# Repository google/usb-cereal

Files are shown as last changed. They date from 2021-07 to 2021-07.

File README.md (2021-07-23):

# USB-Cereal

USB-Cereal is a debugging and development tool for designs that use USB-C port and bring out serial TX/RX lines into SBU1/2 pins. USB-Cereal is made compatible with both 1.8V and 3.3V signalling.

A few important things to note:

* **USB-Cereal is not an officially supported Google product.**

* **USB-Cereal will not work as a USB-C hub/splitter. It is a development tool.**

* **USB-Cereal device is not USB-C spec compliant tool. It will not work with and might damage target devices that hasn't been designed to work with USB-Cereal. Please use with caution and at your own risk.**

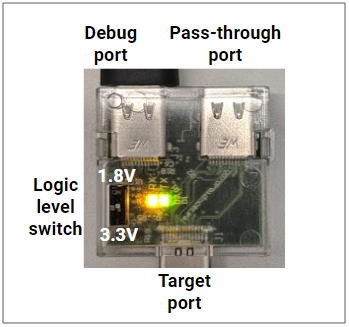
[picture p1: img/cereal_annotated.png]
Cereal Annotated


Please read getting started before plugging in the device. If used without caution, both USB-Cereal and target device could be damaged.

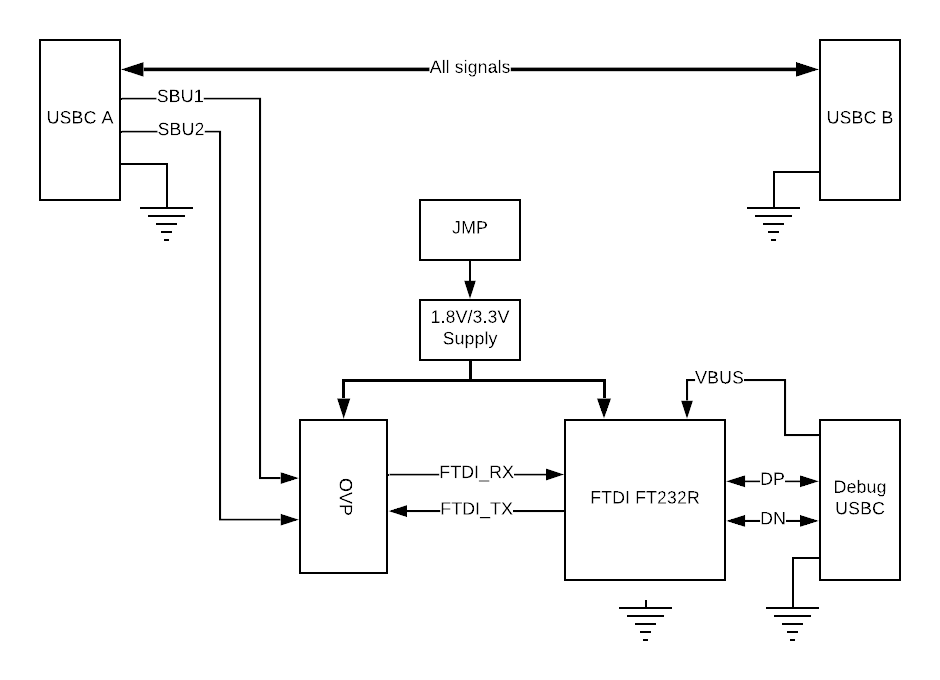
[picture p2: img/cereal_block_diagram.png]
Cereal Block Diagram


# Getting Started
1. Determine correct serial signalling level on the target device - 1.8V or 3.3V. Incorrect voltage setting might permanently damage your device!
2. Determine correct orientation - top vs. bottom - the tool operates correctly only when SBU1 pin corresponds to TX and SBU2 pin corresponds to RX.
3. Serial log capture - please install ftdi232r [drivers](https://www.ftdichip.com/Drivers/VCP.htm). Use your favorite serial monitoring console on the PC.

# Avoid Damaging Target Device
USB-Cereal can operate both with 1.8V and 3.3V logic level systems. The transition from 1.8V to 3.3V is NOT automatic and is done via on-board DIP switch. **Incorrect logic level setting might cause target device or USB-Cereal failure and/or permanent damage. If unsure of target device logic levels used, always start with 1.8V to avoid damaging the target device.** USB-Cereal implements overvoltage clamp transistors, and is unlikely to get damaged from small overvoltage events.

# Source Files
1. Schematic diagram + board layout (Altium)
2. Enclosure (STLs, STEP file exported from Autocad Fusion 360)
3. No firmware/programming is required

# License
This project is licensed under the Apache v2.0 License - see the [LICENSE.md](LICENSE.md) file for details

# Contributing
Thank you for your interest - please review CONTRIBUTING.md!

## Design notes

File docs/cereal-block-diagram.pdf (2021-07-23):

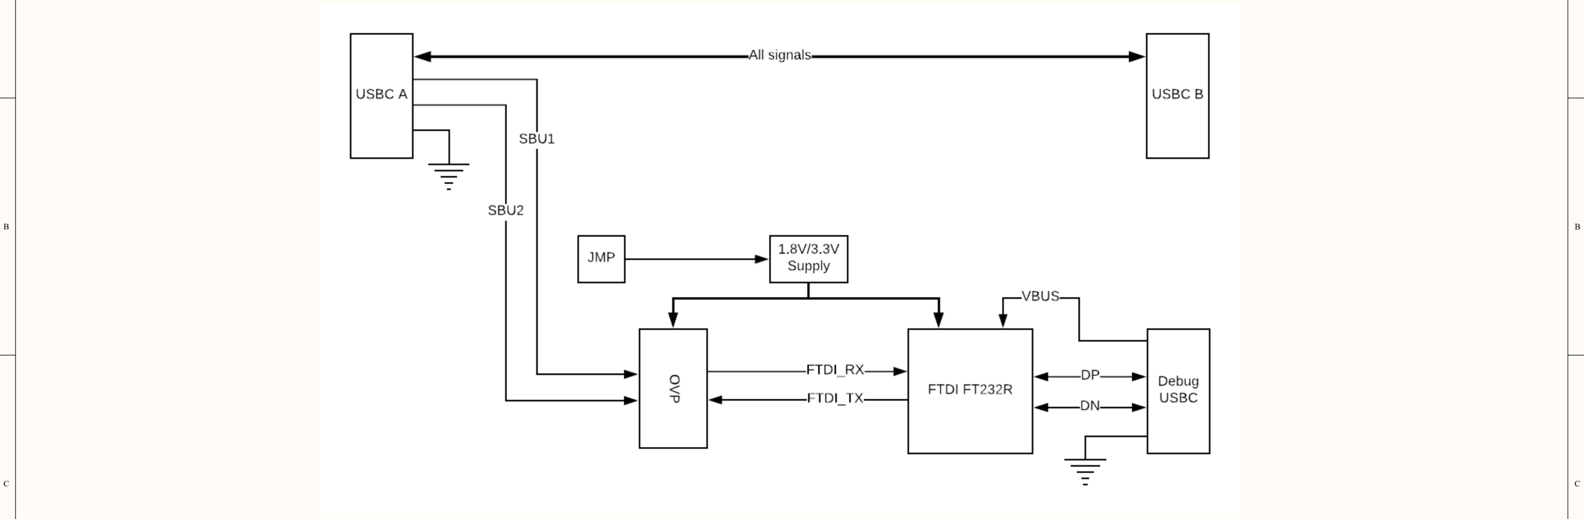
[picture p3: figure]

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
Cereal Diagram

N/A | 1
5/13/2020 | 5:09:34 PM

Title:

GPN: | Size:

Date:

Revision:

Time: | Sheet | of

Tabloid

Author:

Reviewers:

dnv

elerner, jmpenny

Utility board that provides serial interface tapped into SBU lines, compatible with both 1.8V and 3.3V signalling.

Cereal - USB-C serial interface breakout for debugging/development purposes.

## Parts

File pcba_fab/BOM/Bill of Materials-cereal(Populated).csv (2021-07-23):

Comment | Description | Designator | Footprint | LibRef | Quantity
1µF | CAP CER 1UF 6.3V X5R 0201 | C1, C2, C9, C10 | SMD-0201C | GRM033R60J105MEA2D | 4
0.10µF | CAP CER 0.1UF 10V X5R 0201 | C3, C5 | SMD-0201C | GRM033R61A104KE15D | 2
4.7µF | CAP CER 4.7UF 4V X5R 0402 | C4 | SMD-0402C | GRM153R60G475ME15D | 1
10000pF | CAP CER 10000PF 10V X5R 0201 | C6 | SMD-0201C | GRM033R61A103KA01J | 1
2.2µF | CAP CER 2.2UF 10V X5R 0201 | C7, C8 | SMD-0201C | GRM033R61A225KE47D | 2
LTST-C171GKT | LED | D1 | 0805 | LTST-C171GKT | 1
LTST-C171KSKT | LED | D2 | 0805 | LTST-C171KSKT | 1
MBD54DWT1 | Dual Schottky Barrier Diodes, 6-Pin SOT-363, Tape and Reel | D5 | ONSC-SOT-363-6-419B-02_W_V | MBD54DWT1 | 1
632712000011 | USB 3.1 Type C Plug Horizontal SMT WR-COM | J1 | 632712000011 | 632712000011 | 1
632723100011 | USB 3.1 Type C Receptacle Horizontal THR WR-COM | J2, J3 | 632723100011 | 632723100011 | 2
PMDXB600UNEZ | Dual N-Channel Trench MOSFET, 20 V, 0.6 A, -55 to 150 degC, 8-Pin SOT1216 | Q1, Q2 | NXP-SOT1216_N | PMDXB600UNEZ | 2
0.0 | RES SMD 0.0OHM JUMPER 1/20W 0201 | R1, R2, R7, R8, R16 | SMD-0201-RES | ERJ-1GN0R00C | 5
62 | RES SMD 62 OHM 5% 1/10W 0402 | R3, R4 | SMD-0402-RES | ERJ-2GEJ620X | 2
1k | RES SMD 1K OHM 1% 1/20W 0201 | R5 | SMD-0201-RES | ERJ-1GEF1001C | 1
270 | RES SMD 270 OHM 1% 1/20W 0201 | R6 | SMD-0201-RES | ERJ-1GEF2700C | 1
53.6k | RES SMD 53.6K OHM 1% 1/20W 0201 | R9, R10 | SMD-0201-RES | ERJ-1GEF5362C | 2
22.1k | RES SMD 22.1K OHM 1% 1/20W 0201 | R11 | SMD-0201-RES | ERJ-1GEF2212C | 1
30.1k | RES SMD 30.1K OHM 1% 1/20W 0201 | R12, R15, R17, R19 | SMD-0201-RES | ERJ-1GEF3012C | 4
5.1k | RES SMD 5.1K OHM 1% 1/20W 0201 | R18, R20 | SMD-0201-RES | ERJ-1GEF5101C | 2
416131160801 | WS-DISV 1.27 mm small compact SMD Dip Switch with top tape | SW1 | 416131160801 | 416131160801 | 1
ESDR0502NMUTAG | Ultra Low Capacitance ESD Protection Array for High Speed Data Line Protection, 6-Pin UDFN, Pb-Free, Tape and Reel | U1 | ONSC-UDFN-6-517AA-01_V | ESDR0502NMUTAG | 1
TPS77401DGK | Single Output Fast Transient Response LDO, 250 mA, Adjustable 1.5 to 5.5 V Output, 2.7 to 10 V Input, with Power Good Output, 8-pin MSOP (DGK), -40 to 125 degC, Green (RoHS & no Sb/Br) | U2 | TI-DGK8_N | TPS77401DGK | 1
FT232RQ-Reel | USB UART Asynchronous Serial Data Transfer Chip, 32-pin QFN, Tape and Reel | U3 | PQFN5X5-32_V | FT232RQ-Reel | 1

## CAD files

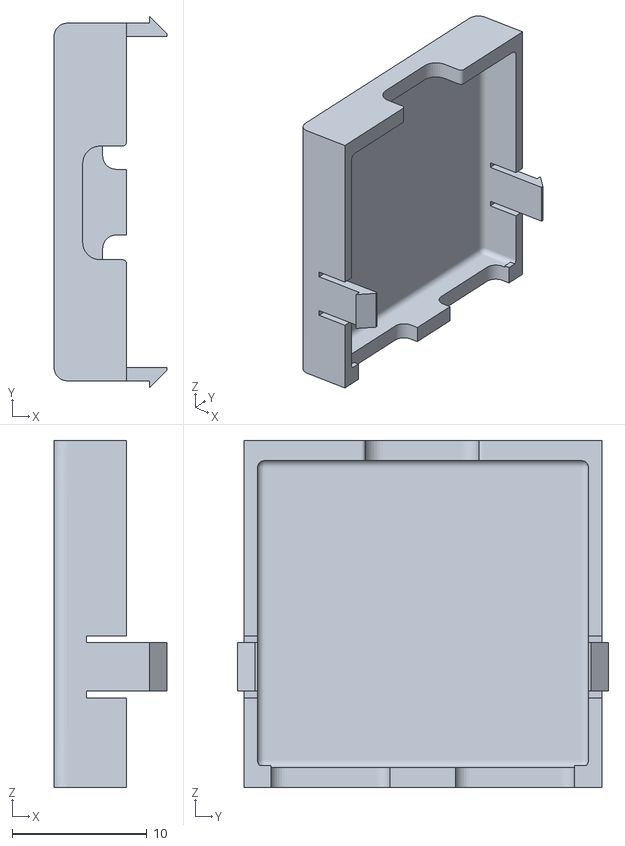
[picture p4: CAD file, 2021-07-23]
mcad/cereal_bottom.stl
8.40 x 27.6 x 25.8

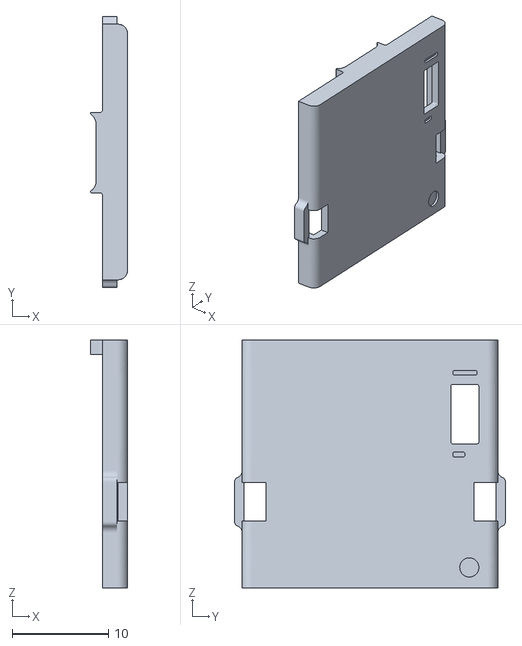
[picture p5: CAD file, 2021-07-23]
mcad/cereal_top.stl
3.87 x 28.2 x 25.8

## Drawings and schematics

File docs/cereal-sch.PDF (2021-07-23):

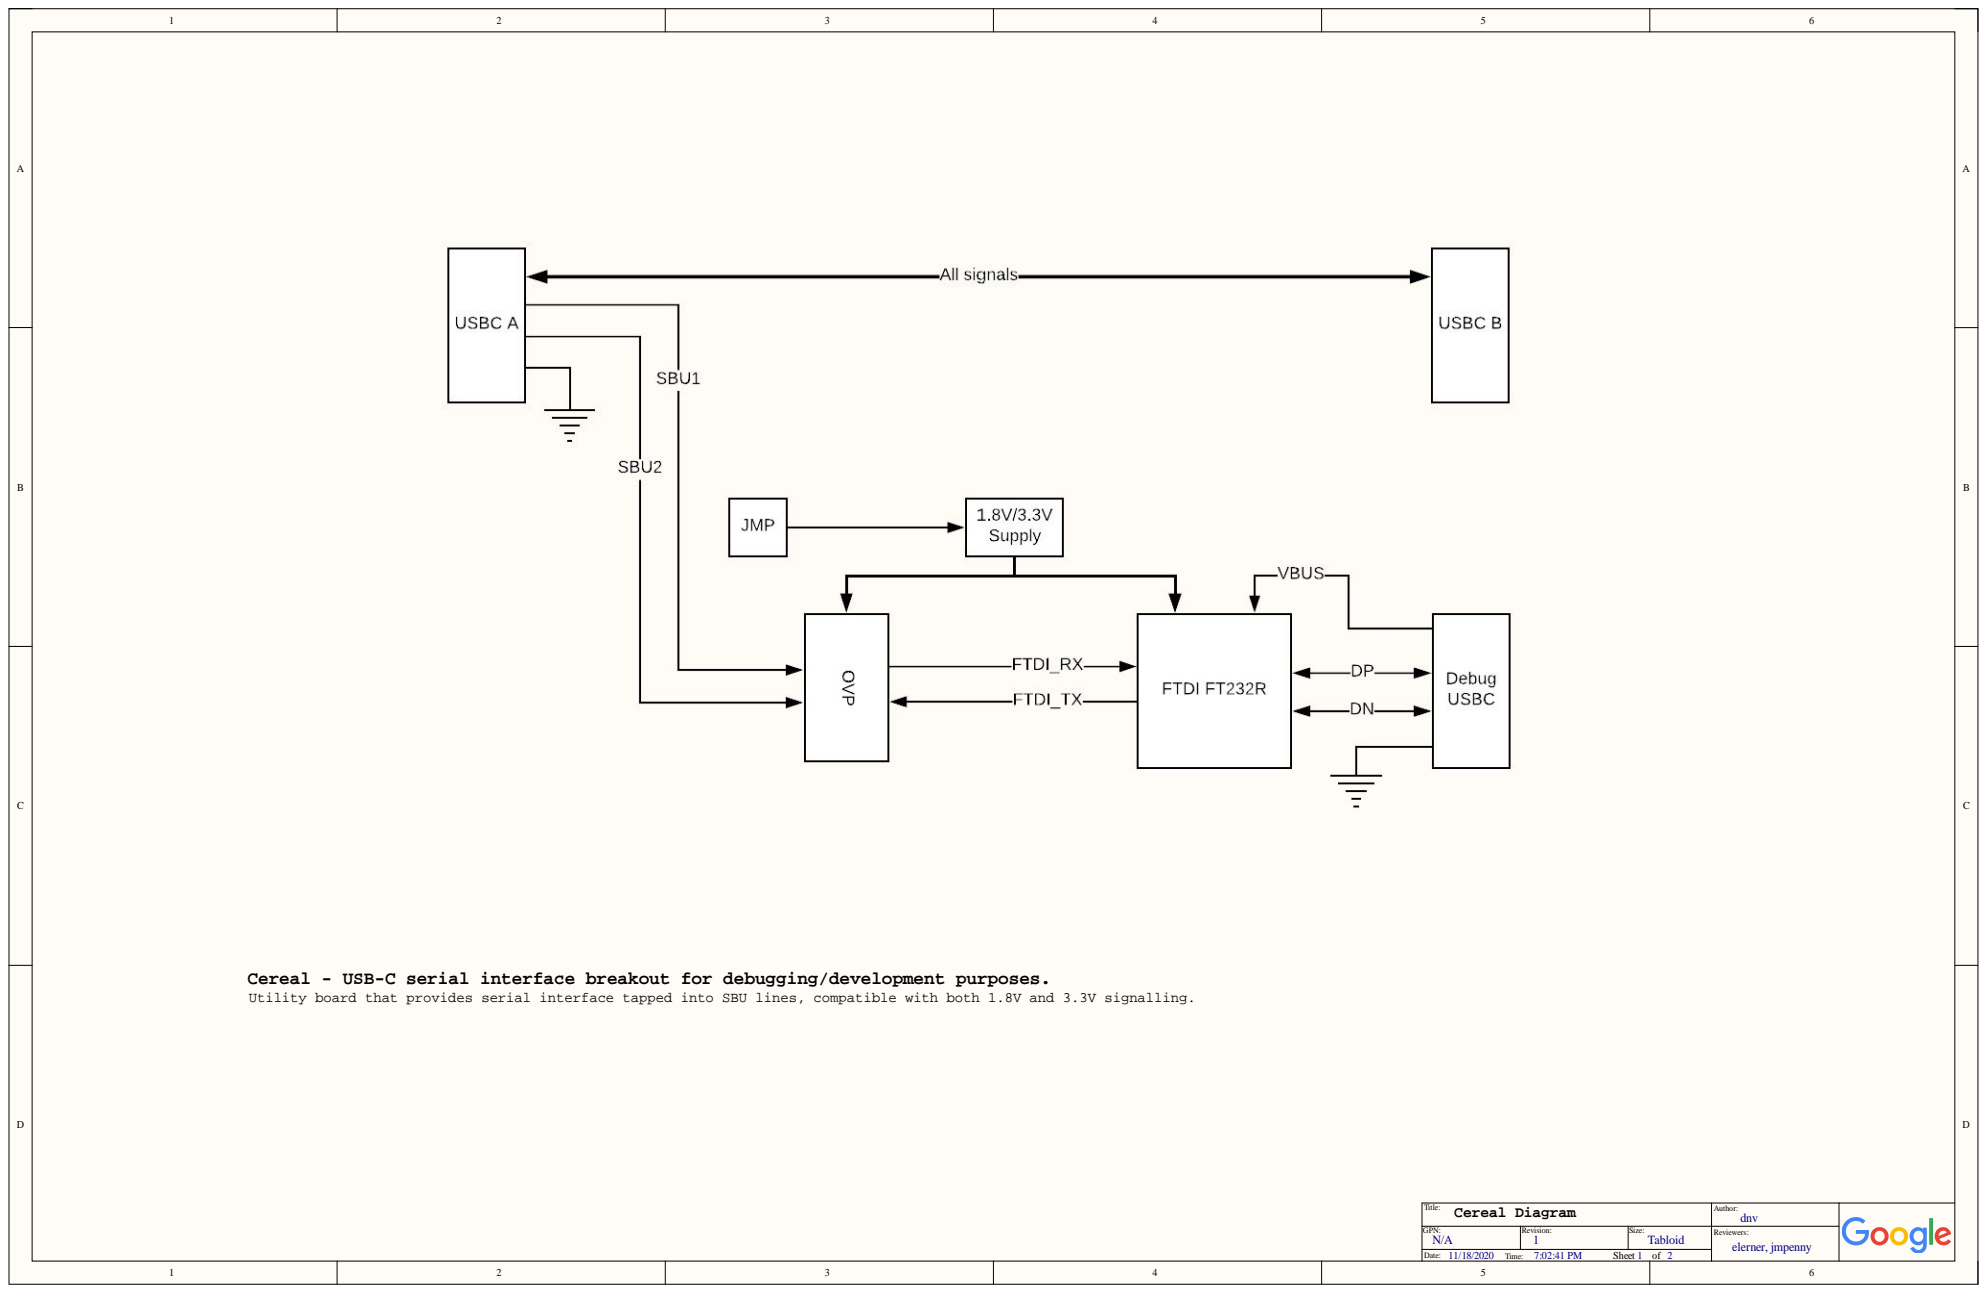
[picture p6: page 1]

Cereal - USB-C serial interface breakout for debugging/development purposes.
Utility board that provides serial interface tapped into SBU lines, compatible with both 1.8V and 3.3V signalling.

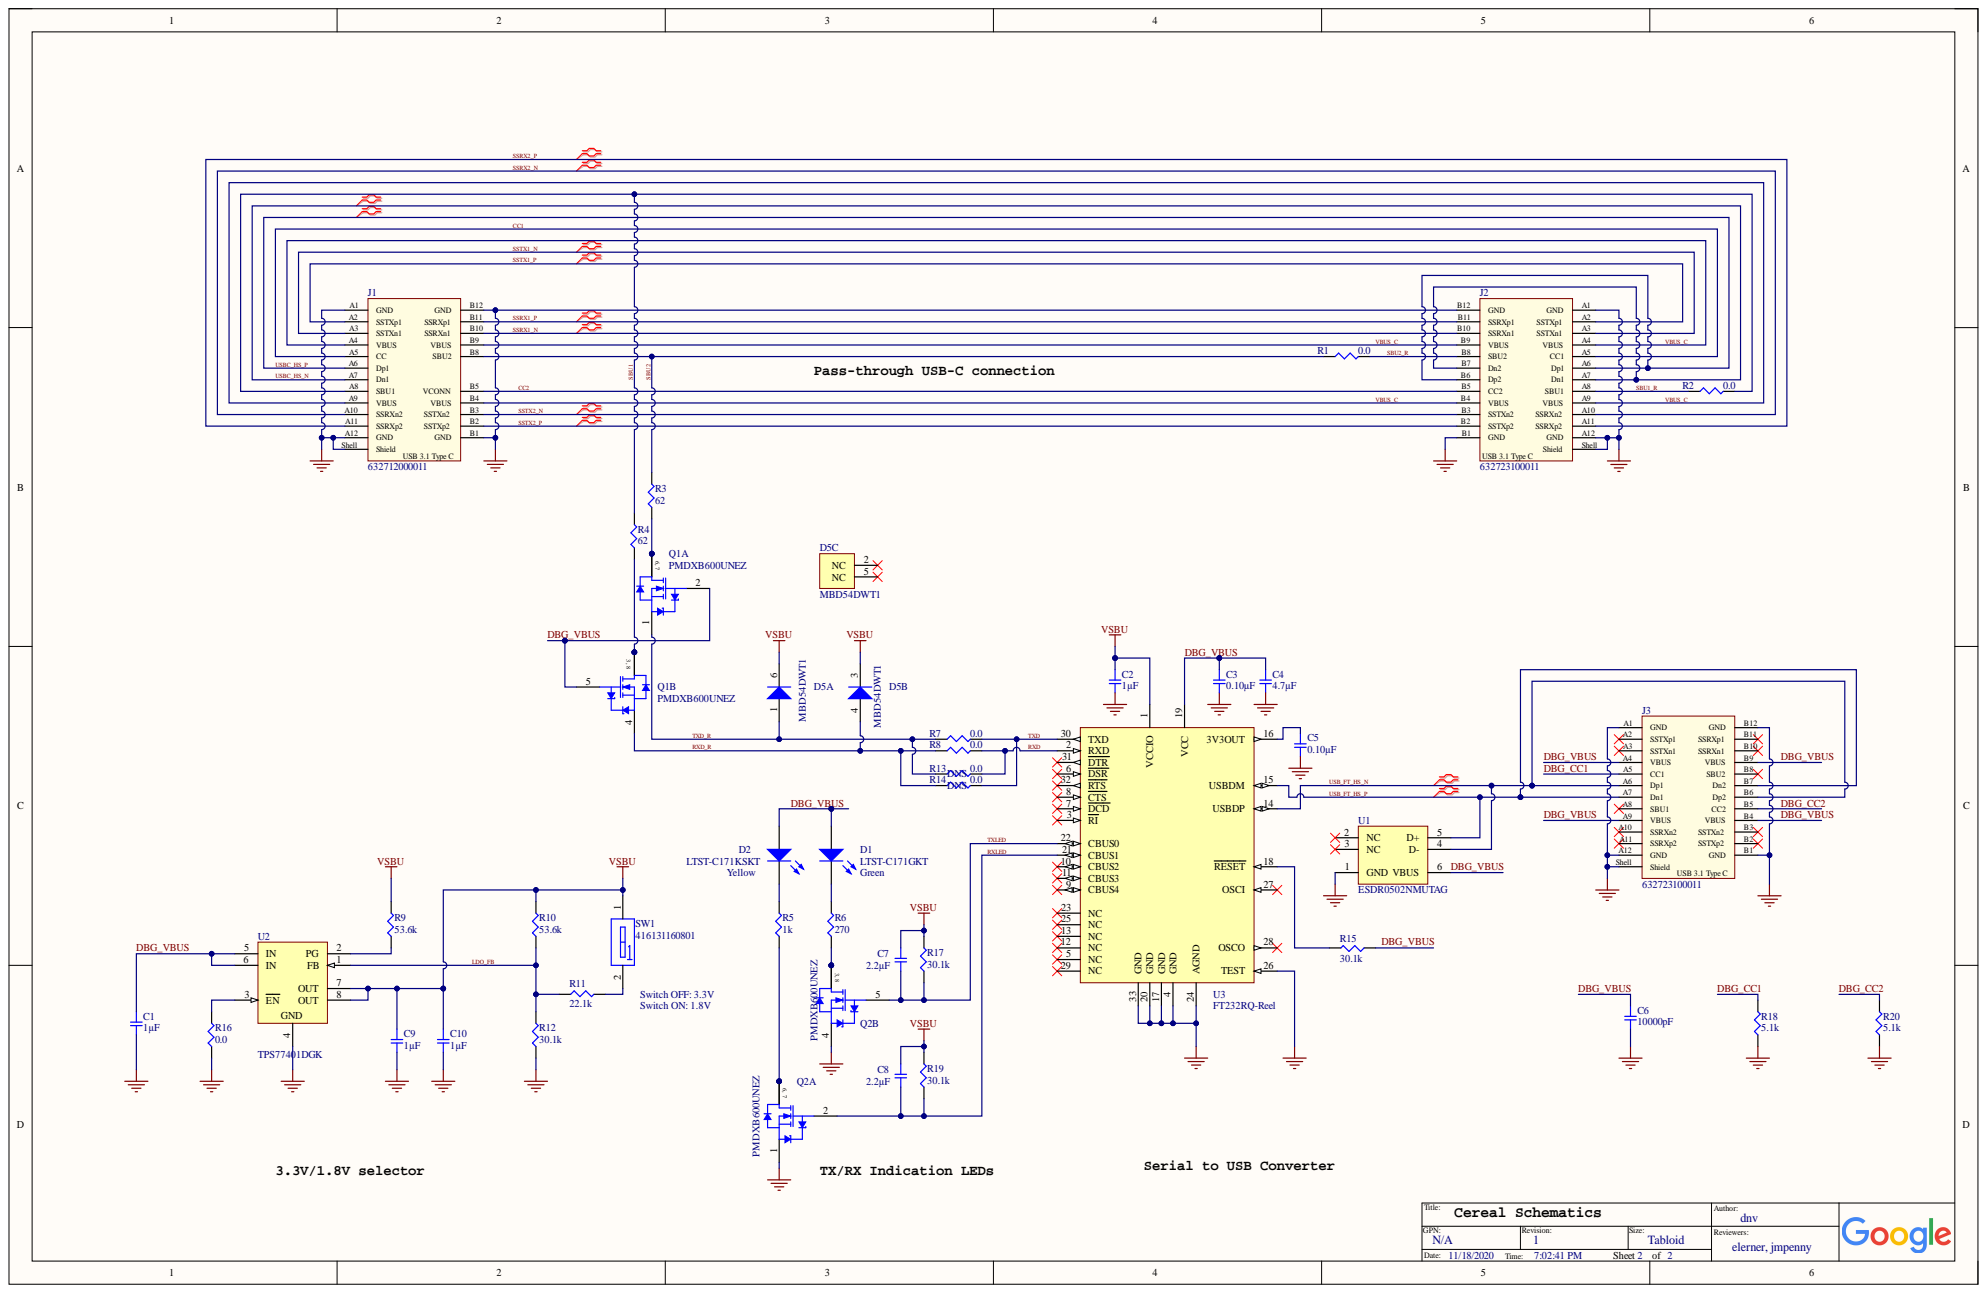
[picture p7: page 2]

Pass-through USB-C connection

USB_FT_HS_P | | Dn1 A7 USB 3.1 Type C

SBU1 A8

U1 | VBUS A9 SSRXn2 A10

Serial to USB Converter
